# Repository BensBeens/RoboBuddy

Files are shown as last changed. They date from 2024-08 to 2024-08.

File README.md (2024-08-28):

# RoboBuddy
Robo companion using RP2040 and other modules.
The plan is to have a robot that is able to change states/faces by reading the accelerometer data. It will have a variety of faces and sounds.
I am first testing the idea on a Raspberry Pi Pico with external modules. Once I finish the prototype I will make the design smaller by making my own PCB with the RP2040.
The software I am using is Thonny for the micropython code and KiCad for the PCB and schematic design.
8/15/2024: I have finished testing it on the pico and have been working on a schematic for the past weeks. I just finished the pcb design and generated the gerber files. I will hopefully begin production soon and see if my pcb works. I will be using JLCPCB.com to make the pcb board.
8/27/2024: Turns out there is an issue with my PCB's Flash memory (it is able to load as an external USB but doesn't load any UF2 files I put in it). I will downscale the project to just be a shield that will connect to a pico. The latest file should be uploaded in the "RoboBuddy Folder" and files named "RoboBuddy.kicad_..."
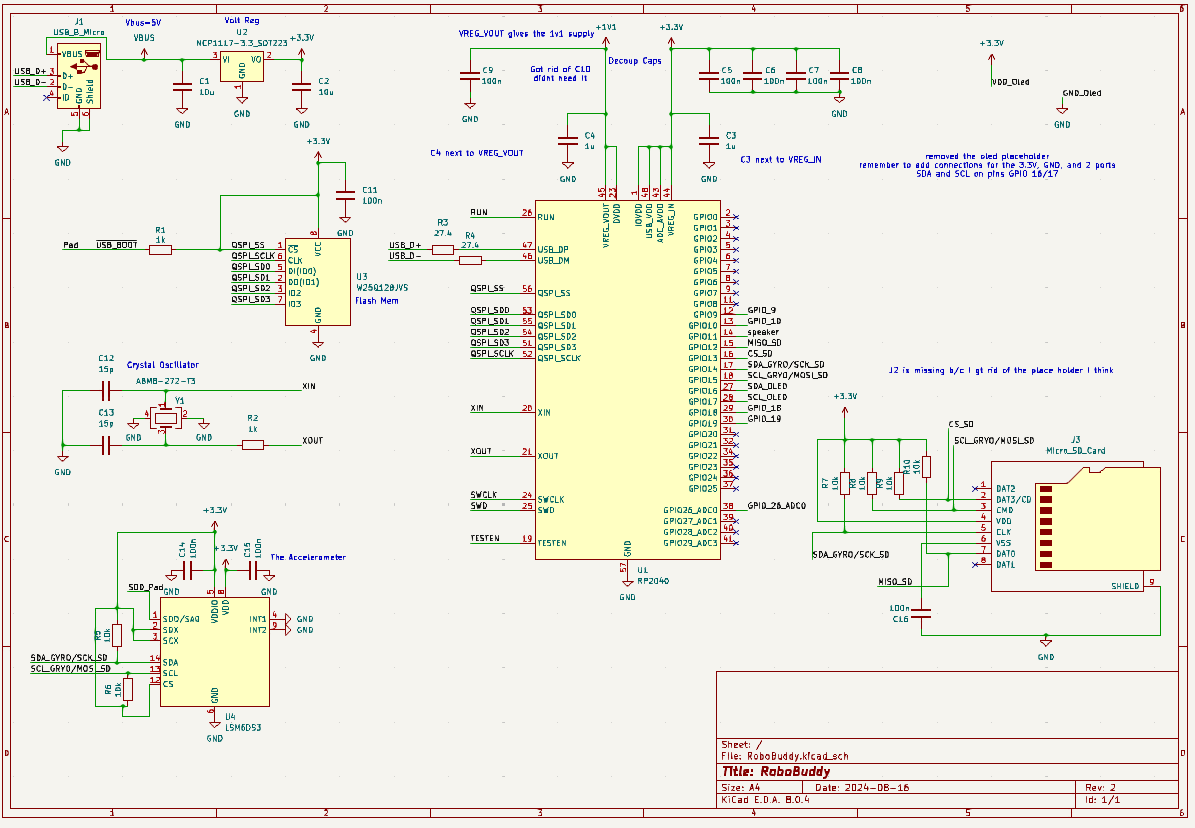
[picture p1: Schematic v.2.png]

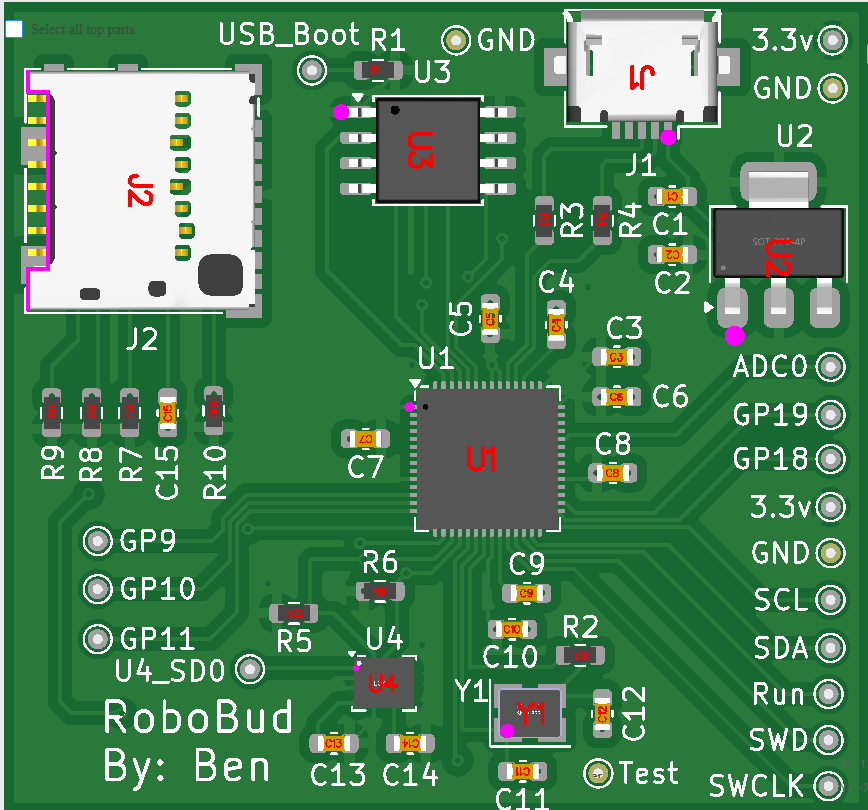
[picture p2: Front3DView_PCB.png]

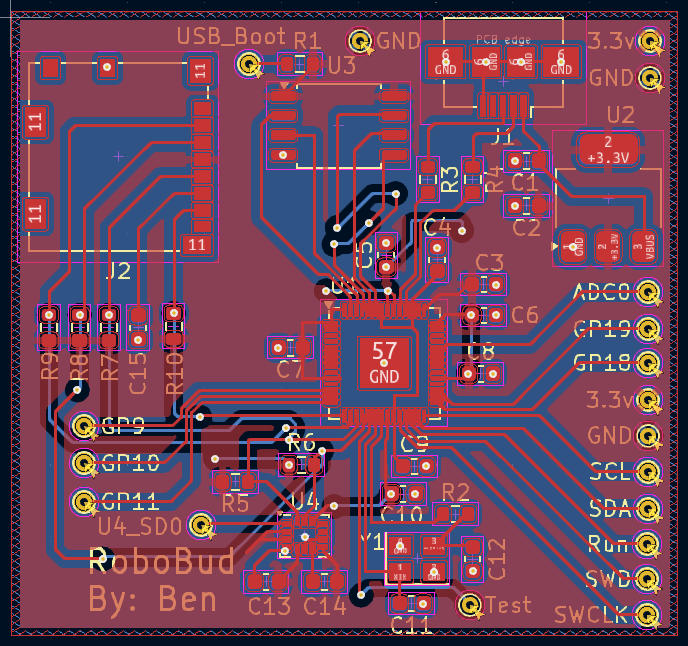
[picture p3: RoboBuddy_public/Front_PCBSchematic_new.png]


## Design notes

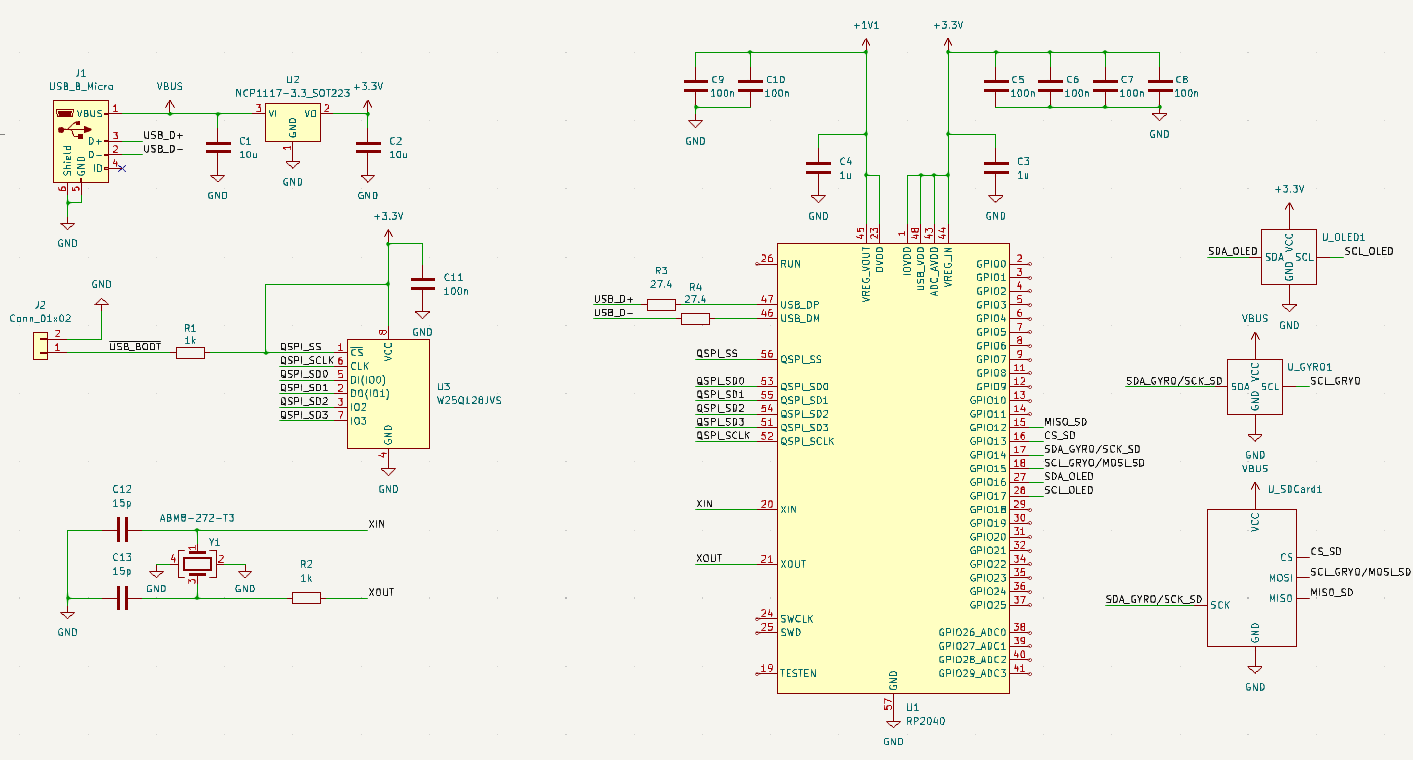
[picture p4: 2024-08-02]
Schematic v.1.png

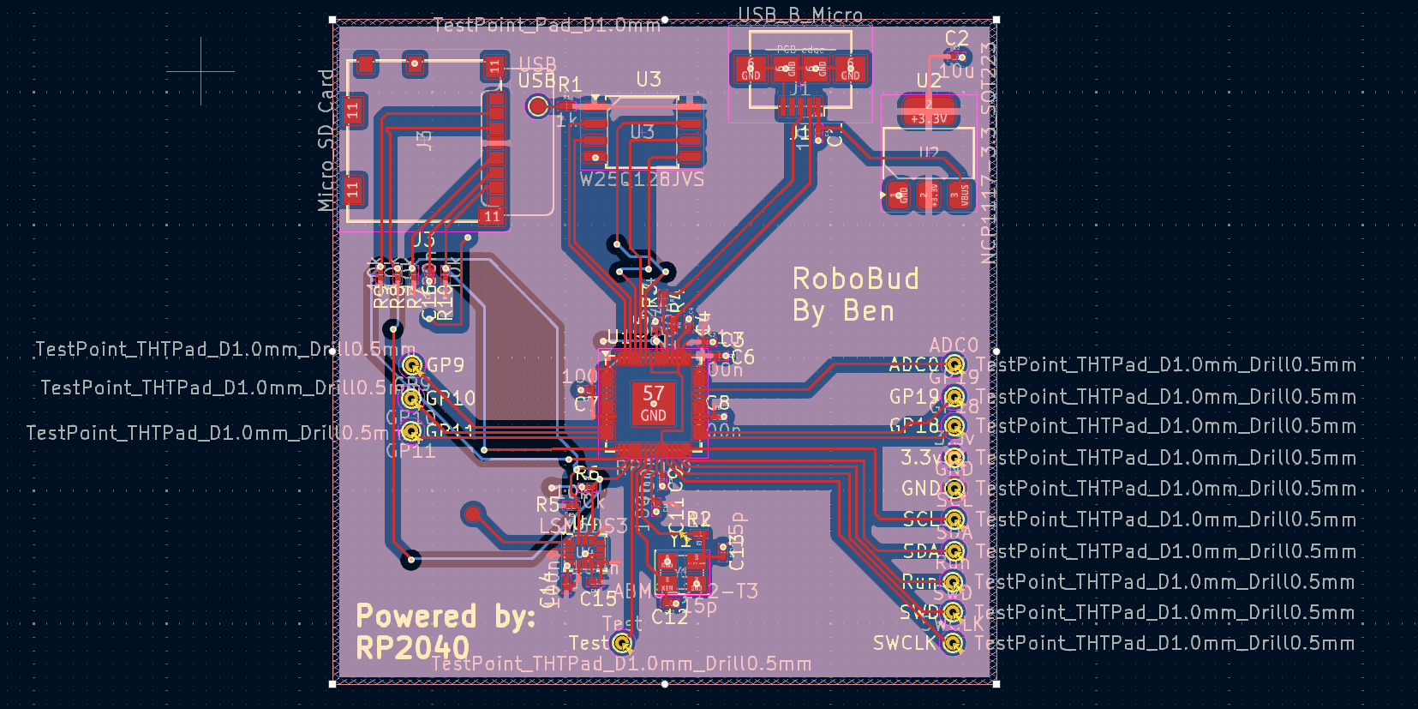
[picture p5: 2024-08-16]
RoboBuddy_public/Front_PCBSchematic.png

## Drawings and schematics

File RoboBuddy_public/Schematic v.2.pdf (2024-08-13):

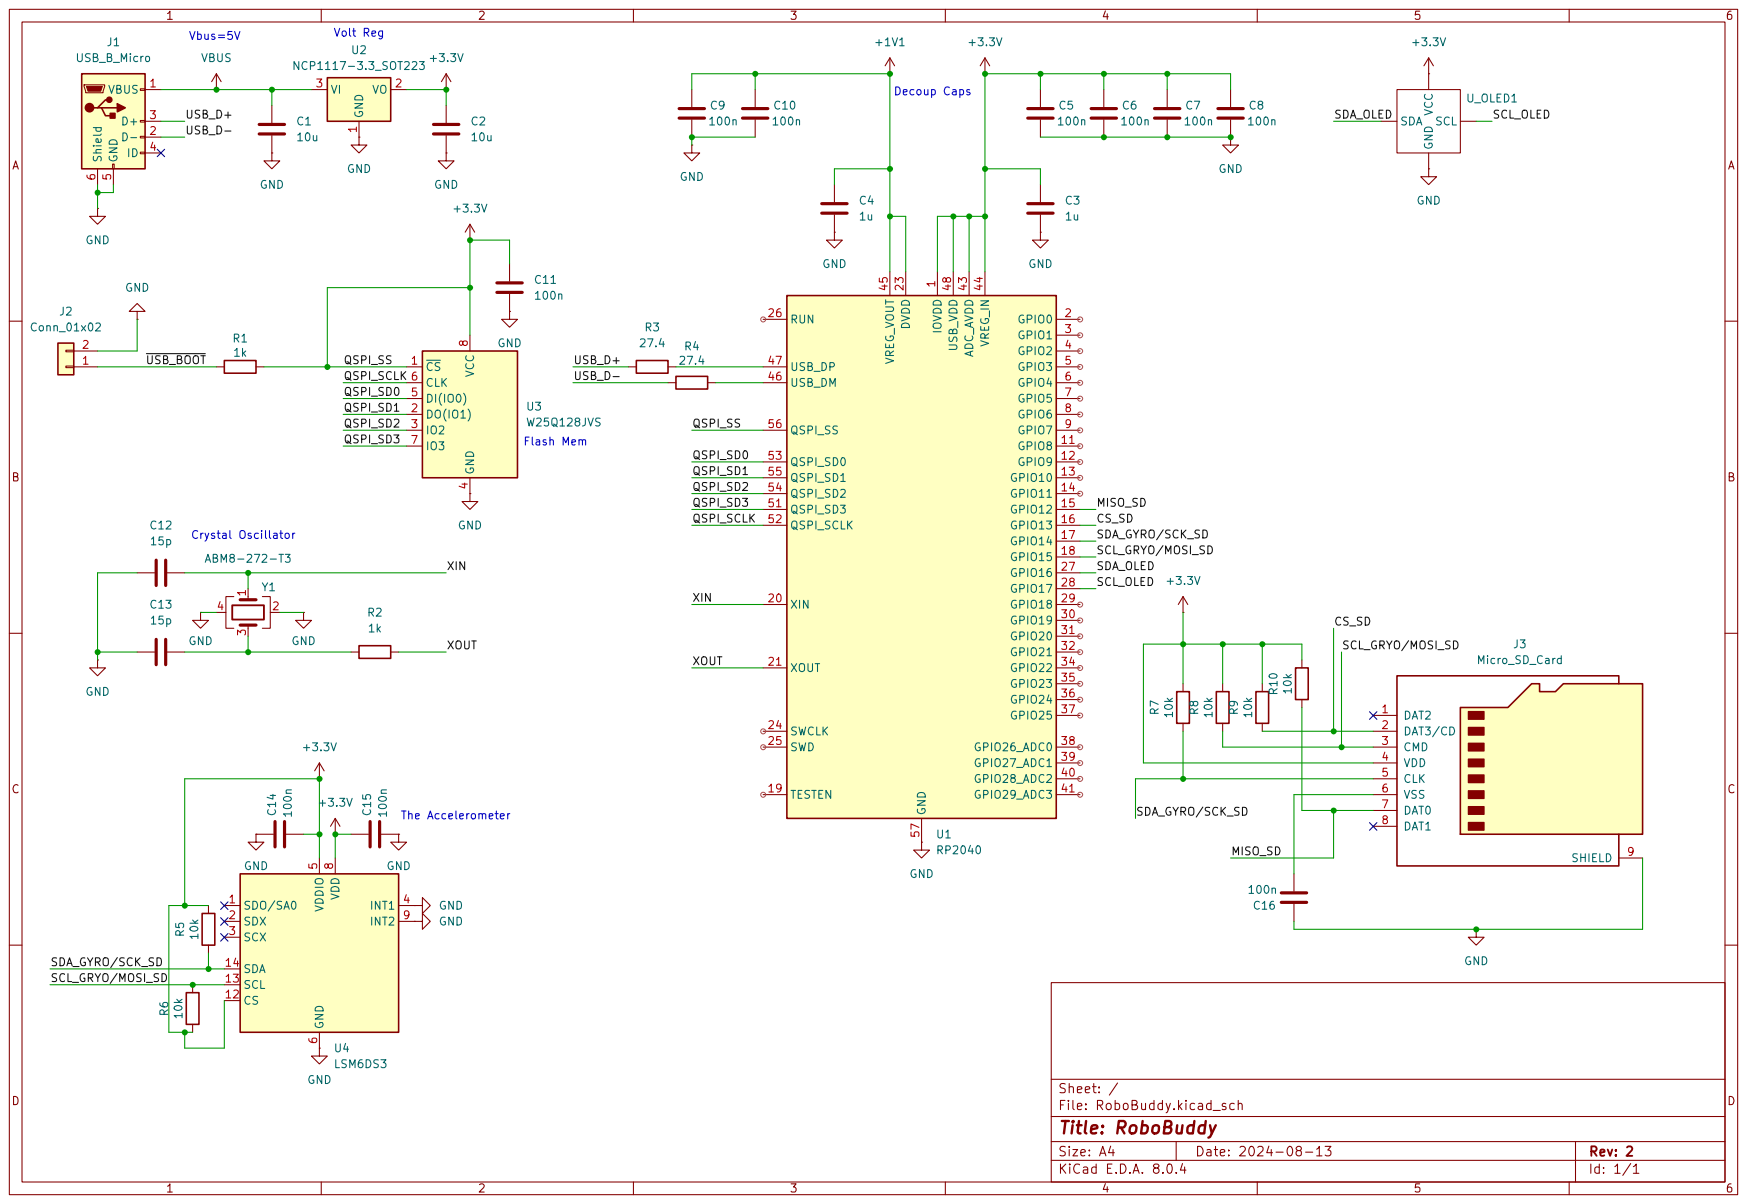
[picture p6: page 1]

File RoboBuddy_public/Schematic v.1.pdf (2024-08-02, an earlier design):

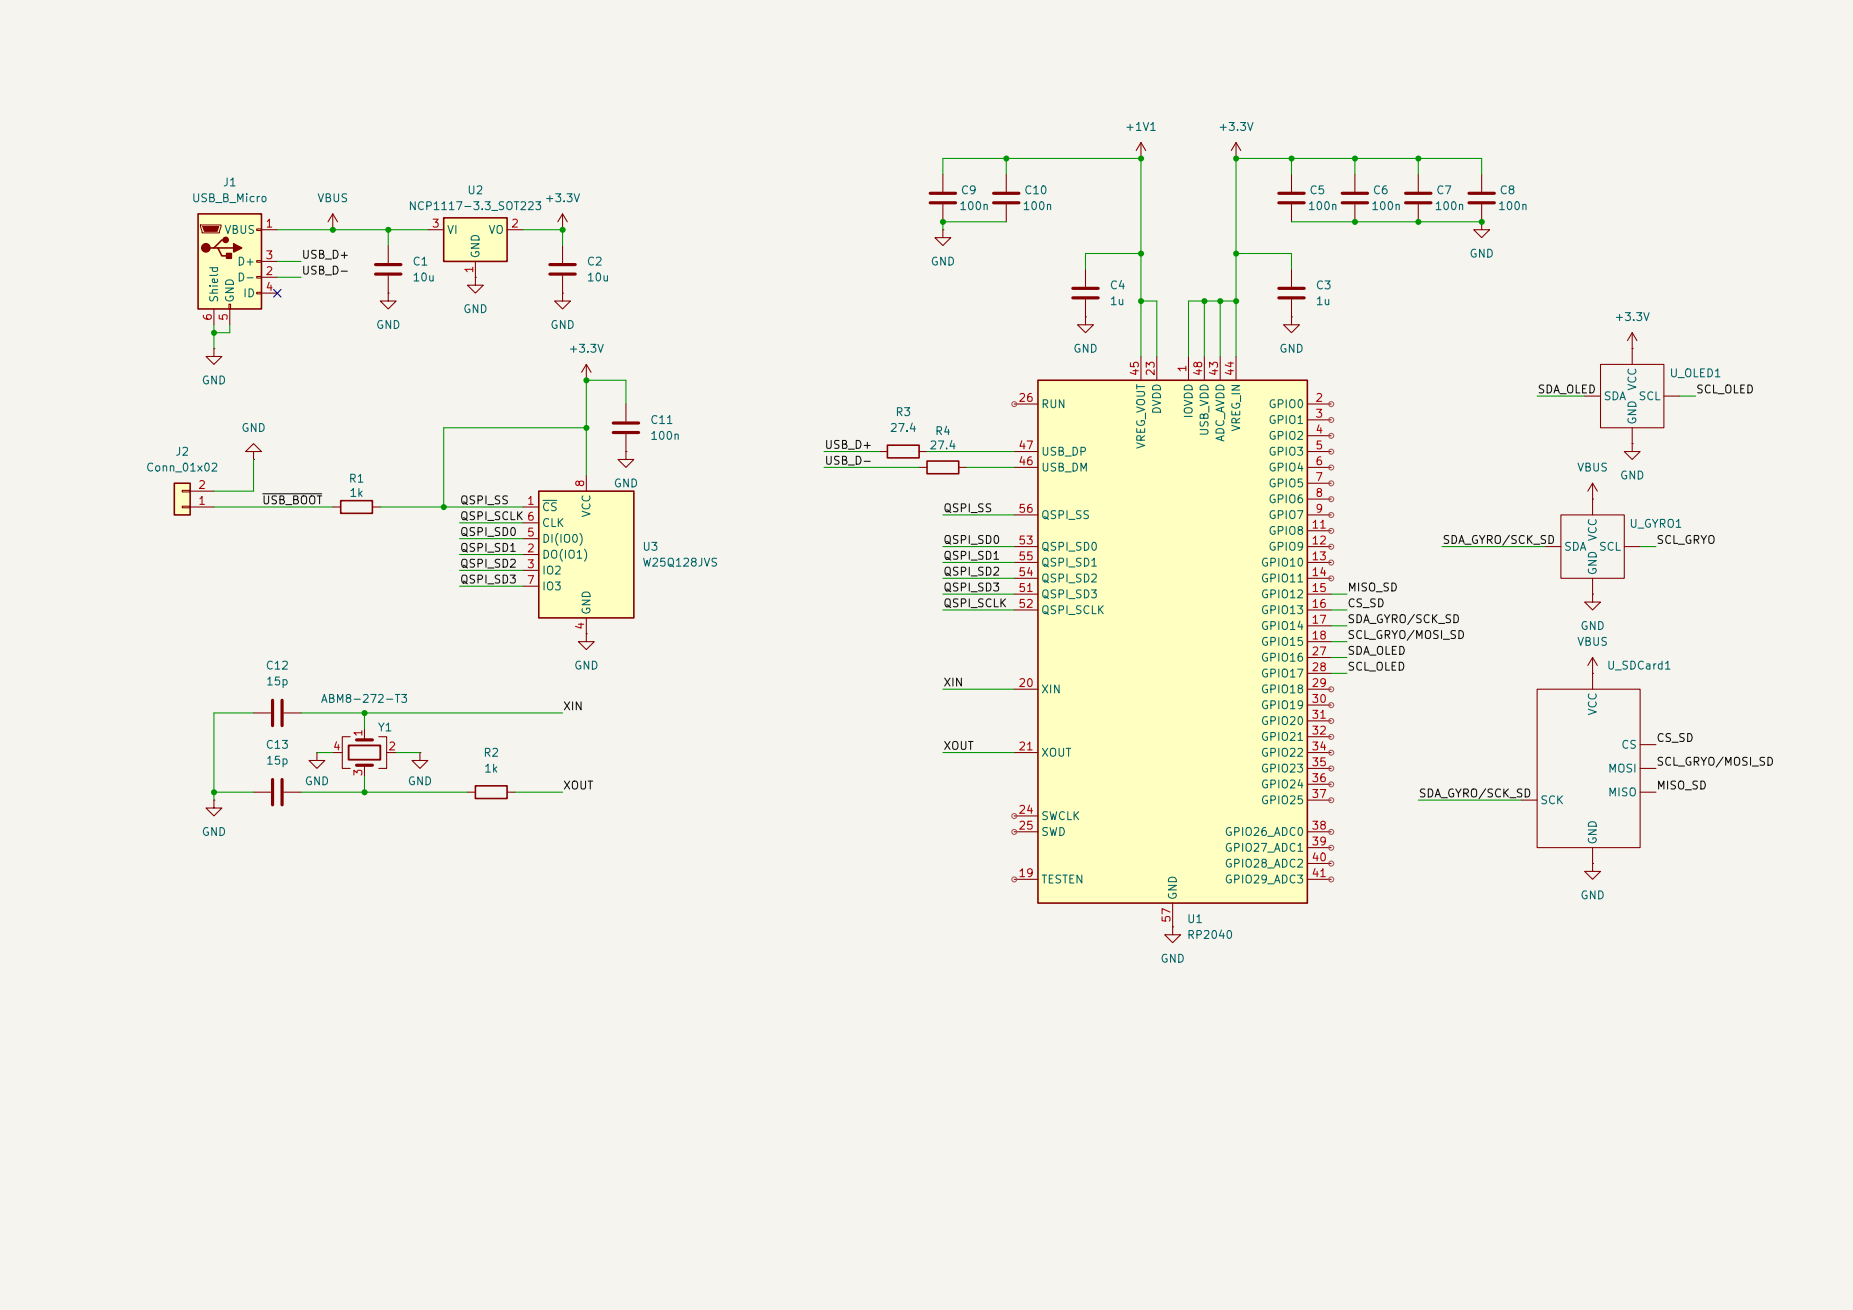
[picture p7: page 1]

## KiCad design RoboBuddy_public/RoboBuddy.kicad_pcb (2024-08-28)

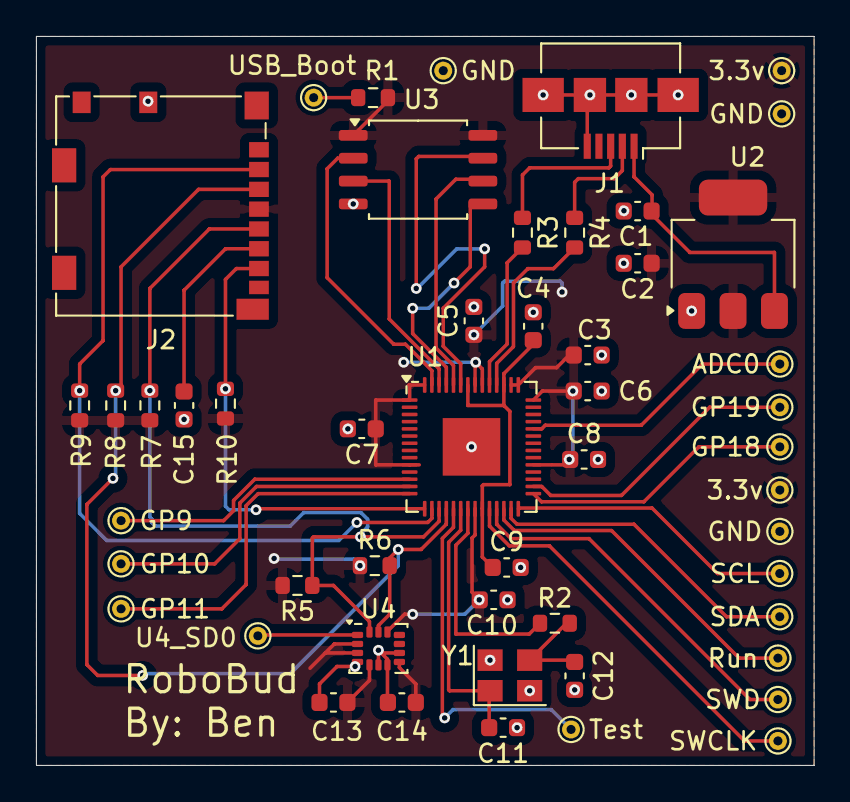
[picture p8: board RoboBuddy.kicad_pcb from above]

Board: 2 copper layers, 43.2 x 40.5 mm, 51 parts (0 on the bottom side), 35 nets.

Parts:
3.3v, 3.3v#2: TestPoint_THTPad_D1.0mm_Drill0.5mm
ADC0: TestPoint_THTPad_D1.0mm_Drill0.5mm
C1, C2: 10u; C_0603_1608Metric
C3, C4: 1u; C_0603_1608Metric
C5, C6, C7, C8, C9, C10, C13, C14, C15: 100n; C_0603_1608Metric
C11, C12: 15p; C_0603_1608Metric
GND: TestPoint_THTPad_D1.0mm_Drill0.5mm
GND#2, GND#3: TestPoint_THTPad_D1.0mm_Drill0.5mm
GP9, GP10, GP11, GP18, GP19: TestPoint_THTPad_D1.0mm_Drill0.5mm
J1: USB_B_Micro; USB_Micro-B_Amphenol_10104110_Horizontal
J2: Micro_SD_Card; microSD_HC_Molex_104031-0811
R1, R2: 1k; R_0603_1608Metric
R3, R4: 27.4; R_0603_1608Metric
R5, R6, R7, R8, R9, R10: 10k; R_0603_1608Metric
Run: TestPoint_THTPad_D1.0mm_Drill0.5mm
SCL: TestPoint_THTPad_D1.0mm_Drill0.5mm
SDA: TestPoint_THTPad_D1.0mm_Drill0.5mm
SWCLK: TestPoint_THTPad_D1.0mm_Drill0.5mm
SWD: TestPoint_THTPad_D1.0mm_Drill0.5mm
Test: TestPoint_THTPad_D1.0mm_Drill0.5mm
U1: RP2040; QFN-56-1EP_7x7mm_P0.4mm_EP3.2x3.2mm
U2: NCP1117-3.3_SOT223; SOT-223-3_TabPin2
U3: W25Q128JVS; SOIC-8_5.23x5.23mm_P1.27mm
U4: LSM6DS3; LGA-14_3x2.5mm_P0.5mm_LayoutBorder3x4y
U4_SD0: TestPoint_THTPad_D1.0mm_Drill0.5mm
USB_Boot: TestPoint_THTPad_D1.0mm_Drill0.5mm
Y1: ABM8-272-T3; Crystal_SMD_3225-4Pin_3.2x2.5mm

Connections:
+1V1: C4.1, C9.1, U1.23 (DVDD), U1.45 (VREG_VOUT), U1.50 (DVDD)
+3.3V: 3.3v.1, 3.3v#2.1, C2.1, C3.1, C5.1, C6.1, C7.1, C8.1, C10.1, C13.2, C14.1, J2.4 (VDD), R1.2, R5.2, R6.1, R7.2, R8.2, R9.2, R10.2, U1.1 (IOVDD), U1.10 (IOVDD), U1.22 (IOVDD), U1.33 (IOVDD), U1.42 (IOVDD), U1.43 (ADC_AVDD), U1.44 (VREG_IN), U1.48 (USB_VDD), U1.49 (IOVDD), U1.56 (QSPI_SS), U2.2 (VO), U3.1 (~CS), U3.8 (VCC), U4.2 (SDX), U4.3 (SCX), U4.5 (VDDIO), U4.8 (VDD), U4.12 (CS)
/CS_SD: J2.2 (DAT3/CD), R9.1, U1.16 (GPIO13)
/GPIO_9: GP9.1, U1.12 (GPIO9)
/GPIO_10: GP10.1, U1.13 (GPIO10)
/GPIO_18: GP18.1, U1.29 (GPIO18)
/GPIO_19: GP19.1, U1.30 (GPIO19)
/GPIO_26_ADC0: ADC0.1, U1.38 (GPIO26_ADC0)
/MISO_SD: J2.7 (DAT0), R10.1, U1.15 (GPIO12)
/Pad: R1.1, USB_Boot.1
/QSPI_SCLK: U1.52 (QSPI_SCLK), U3.6 (CLK)
/QSPI_SD0: U1.53 (QSPI_SD0), U3.5 (DI(IO0))
/QSPI_SD1: U1.55 (QSPI_SD1), U3.2 (DO(IO1))
/QSPI_SD2: U1.54 (QSPI_SD2), U3.3 (IO2)
/QSPI_SD3: U1.51 (QSPI_SD3), U3.7 (IO3)
/RUN: Run.1, U1.26 (RUN)
/SCL_GRYO/MOSI_SD: J2.3 (CMD), R6.2, R8.1, U1.18 (GPIO15), U4.13 (SCL)
/SCL_OLED: SCL.1, U1.28 (GPIO17)
/SD0_Pad: U4.1 (SDO/SA0), U4_SD0.1
/SDA_GYRO/SCK_SD: J2.5 (CLK), R5.1, R7.1, U1.17 (GPIO14), U4.14 (SDA)
/SDA_OLED: SDA.1, U1.27 (GPIO16)
/SWCLK: SWCLK.1, U1.24 (SWCLK)
/SWD: SWD.1, U1.25 (SWD)
/TESTEN: Test.1, U1.19 (TESTEN)
/USB_D+: J1.3 (D+), R3.1
/USB_D-: J1.2 (D-), R4.1
/XIN: C11.2, U1.20 (XIN), Y1.1
/XOUT: R2.2, U1.21 (XOUT)
/speaker: GP11.1, U1.14 (GPIO11)
GND: C1.2, C2.2, C3.2, C4.2, C5.2, C6.2, C7.2, C8.2, C9.2, C10.2, C11.1, C12.1, C13.1, C14.2, C15.1, GND.1, GND#2.1, GND#3.1, J1.5 (GND), J1.6 (Shield), J2.9 (SHIELD), U1.57 (GND), U2.1 (GND), U3.4 (GND), U4.4 (INT1), U4.6 (GND), U4.7 (GND), U4.9 (INT2), Y1.2, Y1.4
unnamed: C12.2, R2.1, Y1.3
unnamed: C15.2, J2.6 (VSS)
unnamed: R4.2, U1.46 (USB_DM)
unnamed: R3.2, U1.47 (USB_DP)
VBUS: C1.1, J1.1 (VBUS), U2.3 (VI)

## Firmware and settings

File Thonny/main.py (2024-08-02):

from machine import Pin, I2C
from ssd1306 import SSD1306_I2C
import framebuf
import time

WIDTH = 128
HEIGHT = 64

i2c = I2C(0, scl = Pin(17), sda = Pin(16), freq=400000)
display = SSD1306_I2C(WIDTH, HEIGHT, i2c)


images = []
for n in range(1, 3):
    with open('/faceAnim/face%s.pbm' % n, 'rb') as f:  #open folder and image
        f.readline() # Magic number
        f.readline() # Creator comment
        f.readline() # Dimensions
        data = bytearray(f.read())
    fbuf = framebuf.FrameBuffer(data, 128, 64, framebuf.MONO_HLSB) #adjust accordingly the width and height
    images.append(fbuf)
    


while True:
    for i in images:
        display.blit(i, 0, 0)
        display.show()
        time.sleep(0.3)

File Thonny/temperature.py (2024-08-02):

from machine import Pin, I2C
from ssd1306 import SSD1306_I2C
import framebuf
import time

WIDTH = 128
HEIGHT = 64

i2c = I2C(0, scl = Pin(17), sda = Pin(16), freq=400000)

display = SSD1306_I2C(128, 64, i2c)

# display.invert(1)
#display.contrast(100)

def read_temp():
    sensor_temp = machine.ADC(4)
    conversion_factor = 3.3 / (65535)
    reading = sensor_temp.read_u16() * conversion_factor 
    temperature = 27 - (reading - 0.706)/0.001721
    formatted_temperature = "{:.1f}".format(temperature)
    string_temperature = str("Temperature:" + formatted_temperature)
    print(string_temperature)
    time.sleep(2)
    return string_temperature


while True:
    display.text('Example 1:',0,0)
    temperature = read_temp()
    display.text(temperature,0,14)
    display.show()
    display.fill(0)
    
    
    

    

  
    

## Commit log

2024-08-02 First upload
    Set up the schematic for the PCB design. RP2040 and external modules are on the schematic. Planning on adding through-hole solder points to attach the external modules to the PCB. (unless I figure ou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
    [RoboBuddy.kicad_pcb, RoboBuddy.kicad_sch]
2024-08-02 First upload of the Thonny code
    Micropython code for Raspberry Pi Pico. I used this code to test on a Pico before ordering my PCB.
2024-08-13 Add files via upload
    Changes:
    - looked at kicad and jlcpcb.com to select some IC to put on my PCB
    - added SD card and gyro/accelerometer IC to PCB schematic
    [RoboBuddy.kicad_sch]
2024-08-13 Add files via upload
    Roughly added the connections and necessary components for Micro SD card reader and Accelerometer/Gyro modules to the RP2040
    - added pullup resistors
    - added decoupling capacitors
    [RoboBuddy.kicad_sch]
2024-08-15 Add files via upload
    Finalized the schematic and started on the pcb design
    [RoboBuddy.kicad_pcb, RoboBuddy.kicad_sch]
2024-08-16 Add files via upload
    Finished the connecting everything on the pcb schematic. I will now get rid of some of the overlapping silkscreen (mainly getting rid of the capacitors and resistors tags)
    [RoboBuddy.kicad_pcb, RoboBuddy.kicad_sch]
2024-08-16 Add files via upload
    Finished removing the unwanted silkscreen and added some additional silkscreen text. Then I generated the gerber files.
    [RoboBuddy_NoSIlkScreen-B_Cu.gbr, RoboBuddy_NoSIlkScreen-B_Mask.gbr, RoboBuddy_NoSIlkScreen-B_Paste.gbr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]
2024-08-16 Add files via upload
    Finalized PCB schematic and sent it to JLCPCB to be manufactured
    [RoboBuddy.kicad_pcb, RoboBuddy.kicad_sch, RoboBuddy_NoSIlkScreen.kicad_pcb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]
2024-08-16 Add files via upload
    did some file cleanup
    [RoboBuddy.kicad_pcb, RoboBuddy.kicad_sch, RoboBuddy_NoSIlkScreen.kicad_pcb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]
